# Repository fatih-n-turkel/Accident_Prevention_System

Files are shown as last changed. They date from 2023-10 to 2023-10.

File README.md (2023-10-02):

# Accident_Prevention_System
Accident Prevention System like TESLA cars. (PCB + Code Design)

(https://www.youtube.com/watch?v=p_svqTvp0FE) As shown in the video, TESLA vehicles prevent accidents by autonomously moving to the most suitable place when they suddenly encounter obstacles. This system has been simulated in this project. It can be used in hobby electronic devices. For example, if the vehicle is driving on a straight road and suddenly detects an obstacle from the left side, it will pass to the right (right corner) if the right side is available. If not, it will move to the most available place, otherwise it will stop.

In the hardware design, I got help from the open source designs of SparkFun.

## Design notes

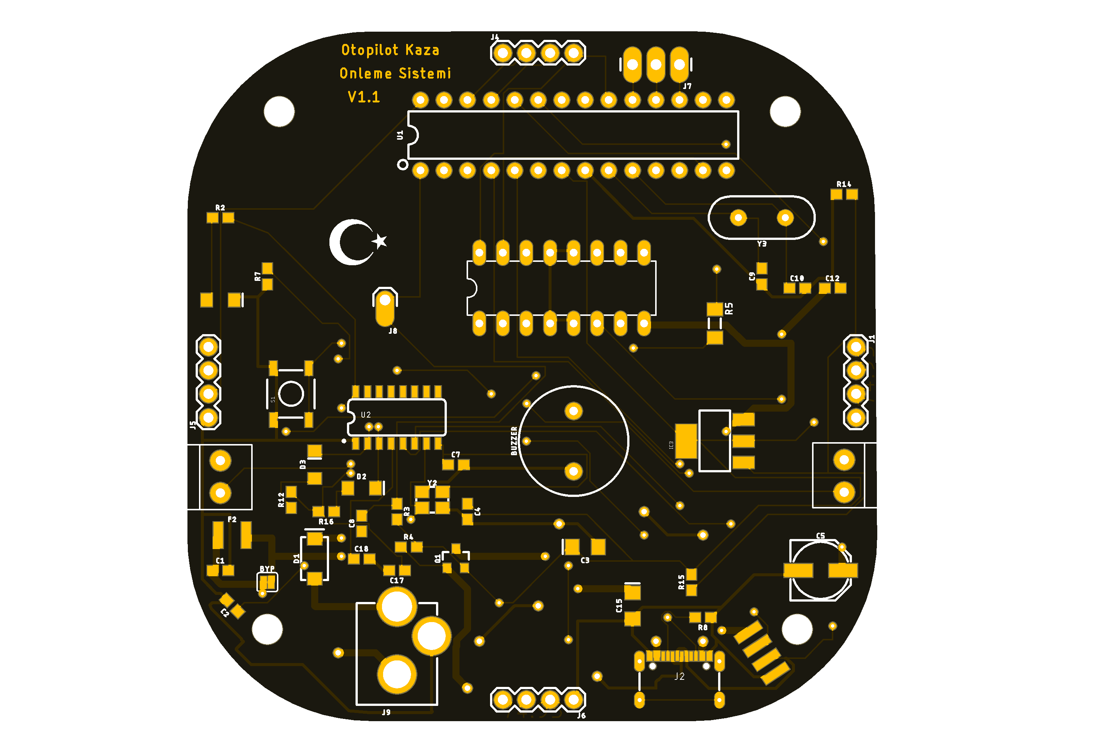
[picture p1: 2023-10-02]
KO_V31.png

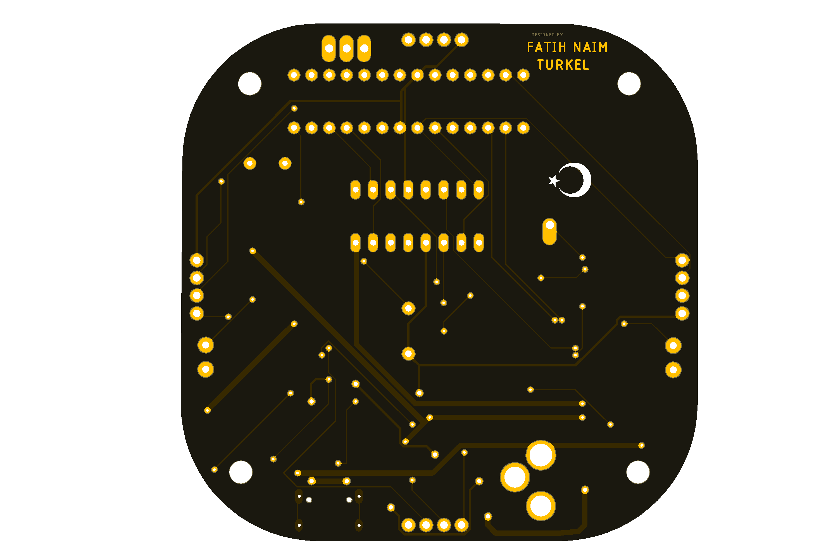
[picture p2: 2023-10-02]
KO_V32.png

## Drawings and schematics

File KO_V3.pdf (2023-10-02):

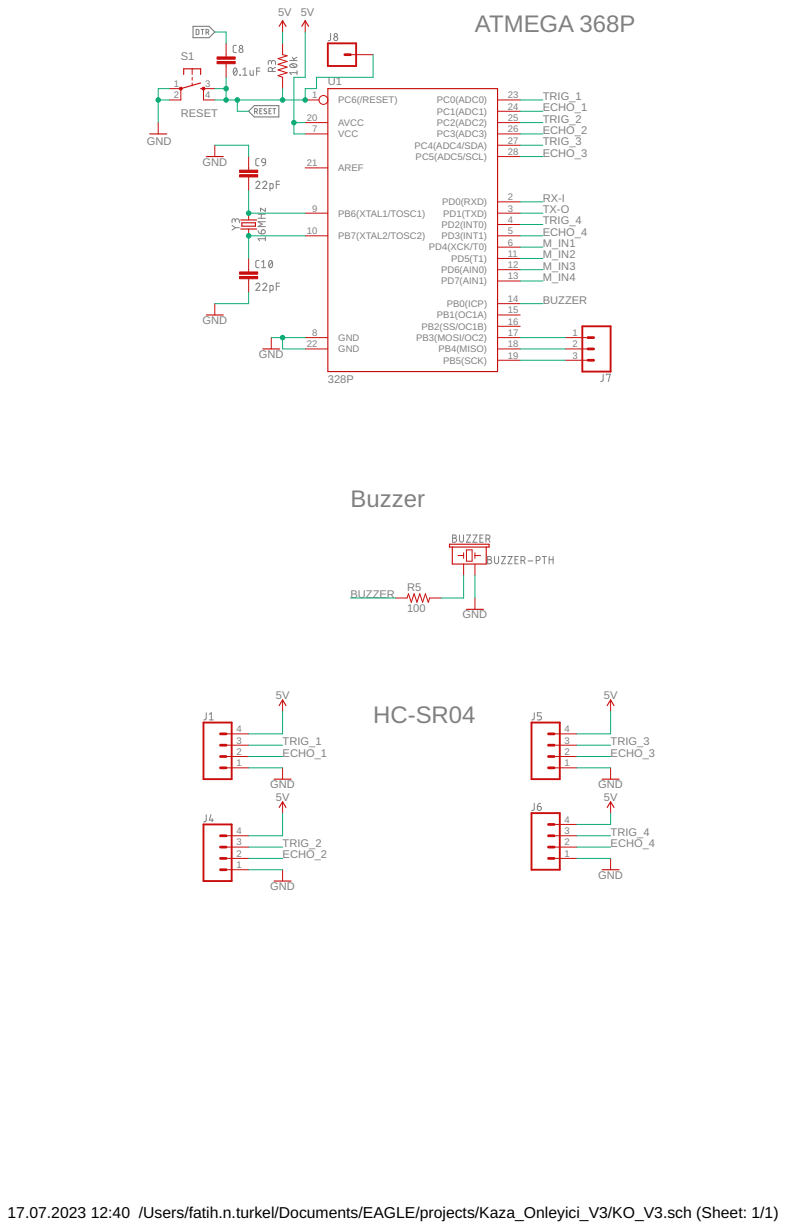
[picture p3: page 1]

17.07.2023 12:40 /Users/fatih.n.turkel/Documents/EAGLE/projects/Kaza_Onleyici_V3/KO_V3.sch (Sheet: 1/1)

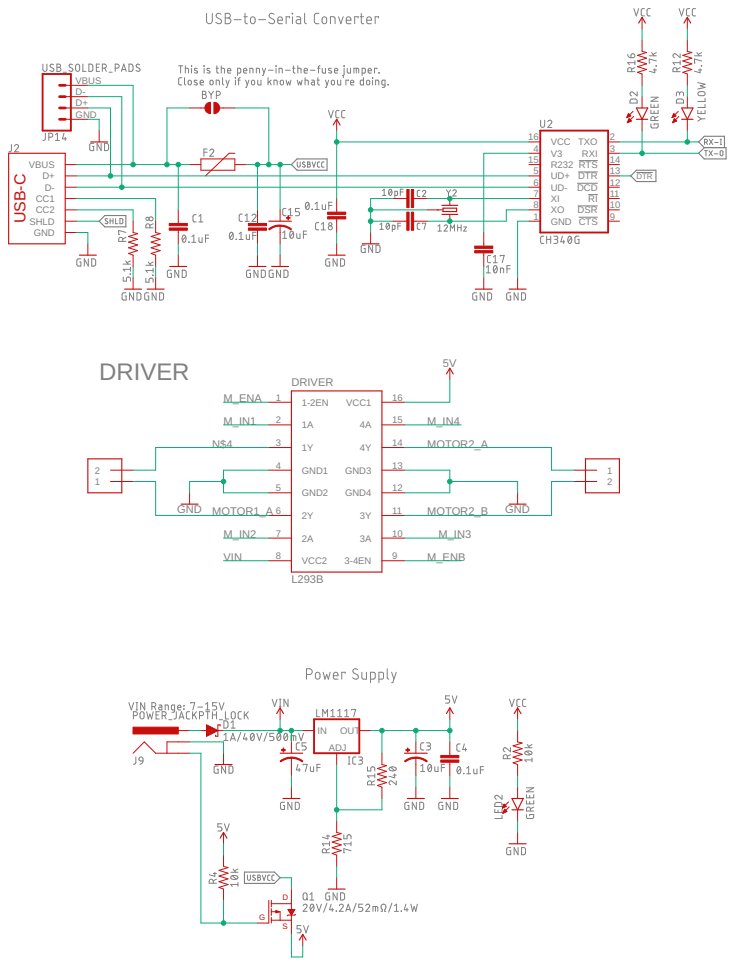
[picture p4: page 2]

DTR U

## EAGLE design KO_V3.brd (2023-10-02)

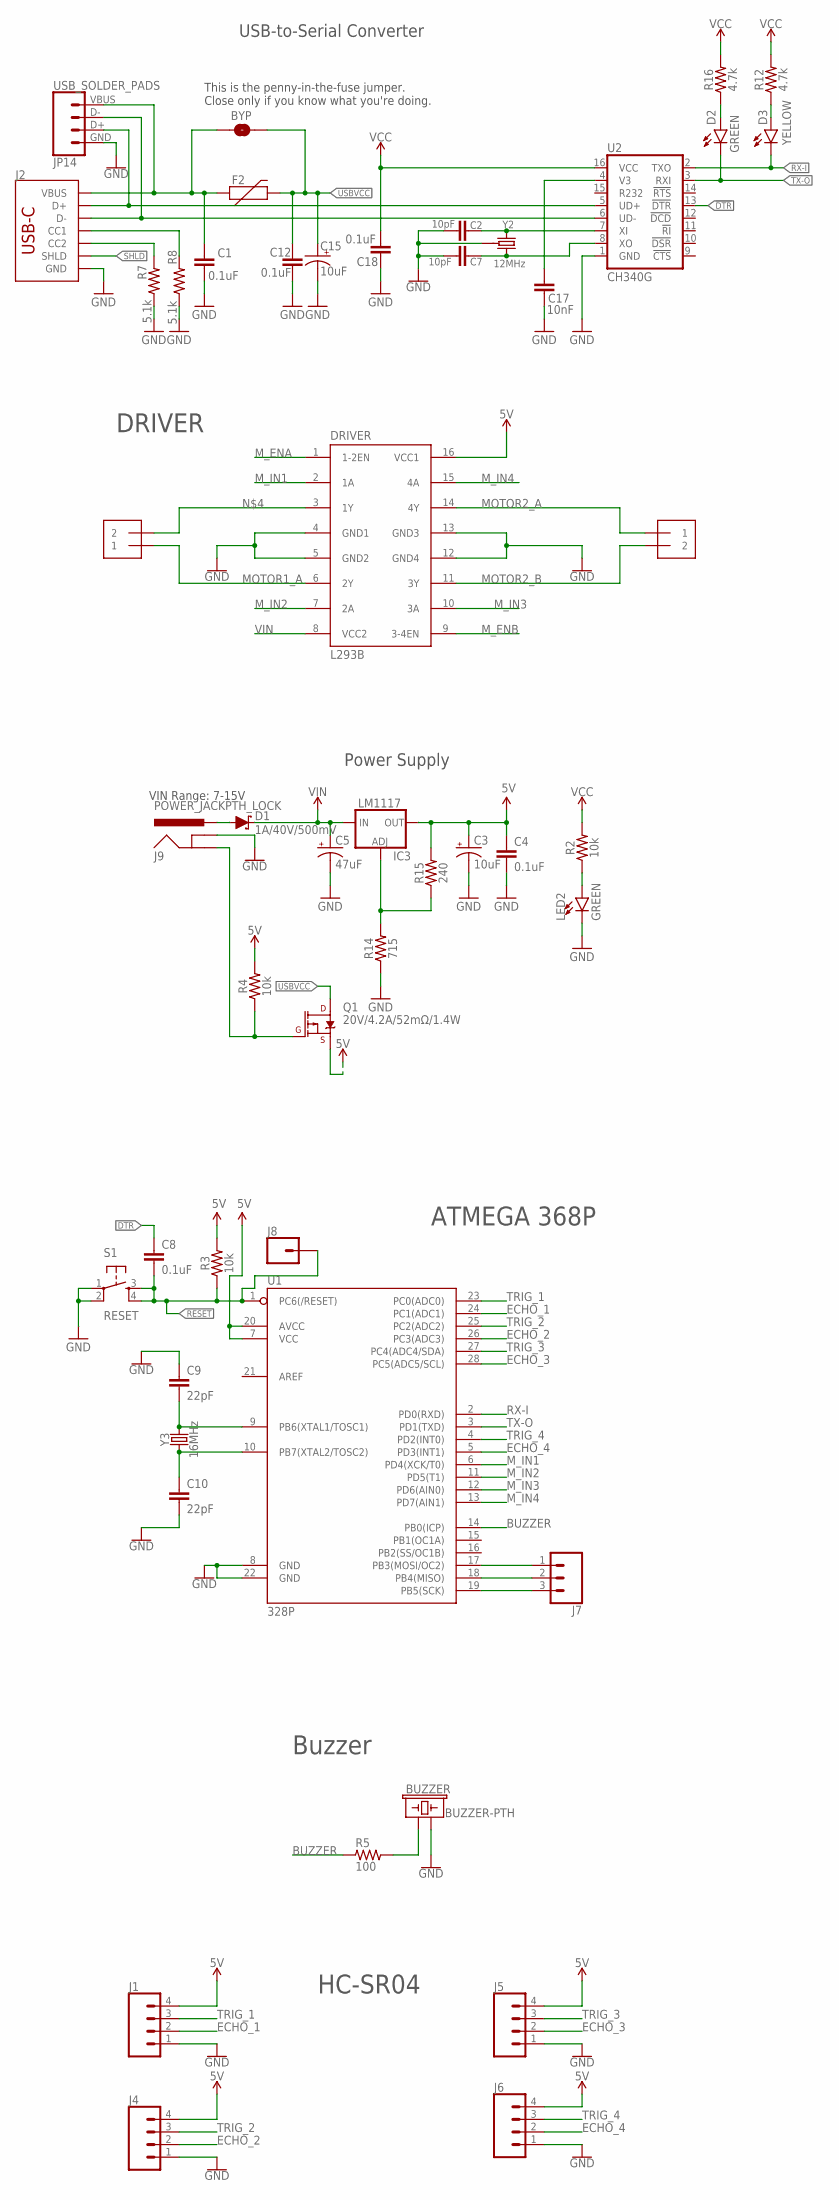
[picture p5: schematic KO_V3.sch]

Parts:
BUZZER: BUZZER-PTH; BUZZER-12MM
BYP: JUMPER-SMT_2_NO_SILK; SMT-JUMPER_2_NO_SILK
C1, C4, C8, C12, C18: 0.1uF; 0603
C2, C7: 10pF; 0603
C3, C15: 10uF; EIA3216
C5: 47uF; PANASONIC_D
C9, C10: 22pF; 0603
C17: 10nF; 0603
D1: 1A/40V/500mV; SMA-DIODE
D2: GREEN; LED-1206
D3: YELLOW; LED-1206-HIDDENSILK
DRIVER: L293B; DIL16
F2: 6V/2A; 1210
IC3: LM1117; SOT223
J1, J4, J5, J6: CONN_04; 1X04
J2: USB Female Type C Connector; USB-C-16P-2LAYER-PADS
J7: CONN_03LONGPADS; 1X03_LONGPADS
J8: CONN_01OFFSET; 1X01_OFFSET
J9: POWER_JACKPTH_LOCK; POWER_JACK_PTH_LOCK
JP14: USB_SOLDER_PADS; USB-SOLDER-PADS
LED2: GREEN; LED-1206
MOTOR_1, MOTOR_2: 1X2-3.5MM
Q1: 20V/4.2A/52mΩ/1.4W; SOT23-3
R2, R3, R4: 10k; 0603
R5: 100; RC-MASTER-SMD_R1206MP
R7, R8: 5.1k; 0603
R12, R16: 4.7k; 0603
R14: 715; 0603
R15: 240; 0603
S1: RESET; TACTILE-SWITCH-SMD
U1: 328P; DIP28
U2: CH340G; SO016
Y2: 12MHz; CRYSTAL-SMD-3.2X2.5MM
Y3: 16MHz; HC49US

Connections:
5V: C3.+, C4.1, DRIVER.16 (VCC1), IC3.2 (OUT), IC3.4 (OUT), J1.4, J4.4, J5.4, J6.4, Q1.2 (S), R3.2, R4.2, R15.2, U1.7 (VCC), U1.20 (AVCC)
!DTR!: U2.13 (!DTR)
BUZZER: R5.1, U1.14 (PB0(ICP))
CC1: J2.A5 (CC1), R8.2
CC2: J2.B5 (CC2), R7.2
D+: J2.A6 (D+), J2.B6 (D+), JP14.D+ (3), U2.5 (UD+)
D-: J2.A7 (D-), J2.B7 (D-), JP14.D- (2), U2.6 (UD-)
DTR: C8.1
ECHO_1: J1.2, U1.24 (PC1(ADC1))
ECHO_2: J4.2, U1.26 (PC3(ADC3))
ECHO_3: J5.2, U1.28 (PC5(ADC5/SCL))
ECHO_4: J6.2, U1.5 (PD3(INT1))
GND: BUZZER.- (2), C1.2, C2.2, C3.-, C4.2, C5.-, C7.2, C9.1, C10.2, C12.2, C15.-, C17.2, C18.2, DRIVER.4 (GND1), DRIVER.5 (GND2), DRIVER.12 (GND4), DRIVER.13 (GND3), J1.1, J2.GND, J2.GND2 (GND), J4.1, J5.1, J6.1, J9.GNDBREAK, JP14.GND (4), LED2.C, R7.1, R8.1, R14.1, S1.1, S1.2, U1.8 (GND), U1.22 (GND), U2.1 (GND), Y2.2 (GND), Y2.4 (GND)
INSERT: J9.GND, Q1.1 (G), R4.1
MOTOR1_A: DRIVER.6 (2Y), MOTOR_2.1
MOTOR2_A: DRIVER.14 (4Y), MOTOR_1.1
MOTOR2_B: DRIVER.11 (3Y), MOTOR_1.2
M_ENA: DRIVER.1 (1-2EN)
M_ENB: DRIVER.9 (3-4EN)
M_IN1: DRIVER.2 (1A), U1.6 (PD4(XCK/T0))
M_IN2: DRIVER.7 (2A), U1.11 (PD5(T1))
M_IN3: DRIVER.10 (3A), U1.12 (PD6(AIN0))
M_IN4: DRIVER.15 (4A), U1.13 (PD7(AIN1))
unnamed: C17.1, U2.4 (V3)
unnamed: C7.1, U2.8 (XO), Y2.3 (2)
unnamed: LED2.A, R2.1
unnamed: DRIVER.3 (1Y), MOTOR_2.2
unnamed: D2.A, R16.1
unnamed: BUZZER.+ (1), R5.2
unnamed: C2.1, U2.7 (XI), Y2.1
unnamed: D3.A, R12.1
unnamed: C9.2, U1.9 (PB6(XTAL1/TOSC1)), Y3.2
unnamed: C10.1, U1.10 (PB7(XTAL2/TOSC2)), Y3.1
unnamed: IC3.1 (ADJ), R14.2, R15.1
unnamed: J7.3, U1.19 (PB5(SCK))
unnamed: J7.2, U1.18 (PB4(MISO))
unnamed: J7.1, U1.17 (PB3(MOSI/OC2))
PWRIN: D1.A, J9.PWR
RESET: C8.2, J8.1, R3.1, S1.3, S1.4, U1.1 (PC6(/RESET))
RX-I: D3.C, U1.2 (PD0(RXD)), U2.2 (TXO)
SHLD: J2.SHLD1 (SHLD), J2.SHLD2 (SHLD), J2.SHLD3 (SHLD), J2.SHLD4 (SHLD)
TRIG_1: J1.3, U1.23 (PC0(ADC0))
TRIG_2: J4.3, U1.25 (PC2(ADC2))
TRIG_3: J5.3, U1.27 (PC4(ADC4/SDA))
TRIG_4: J6.3, U1.4 (PD2(INT0))
TX-O: D2.C, U1.3 (PD1(TXD)), U2.3 (RXI)
USBVCC: BYP.2, C12.1, C15.+, F2.2, Q1.3 (D)
VCC: C18.1, R2.2, R12.2, R16.2, U2.16 (VCC)
VIN: C5.+, D1.C, DRIVER.8 (VCC2), IC3.3 (IN)
VUSB: BYP.1, C1.1, F2.1, J2.VBUS1 (VBUS), J2.VBUS2 (VBUS), JP14.VBUS (1)

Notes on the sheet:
DRIVER
HC-SR04
Buzzer
ATMEGA 368P
USB-to-Serial Converter
This is the penny-in-the-fuse jumper. Close only if you know what you're doing.
Power Supply
VIN Range: 7-15V

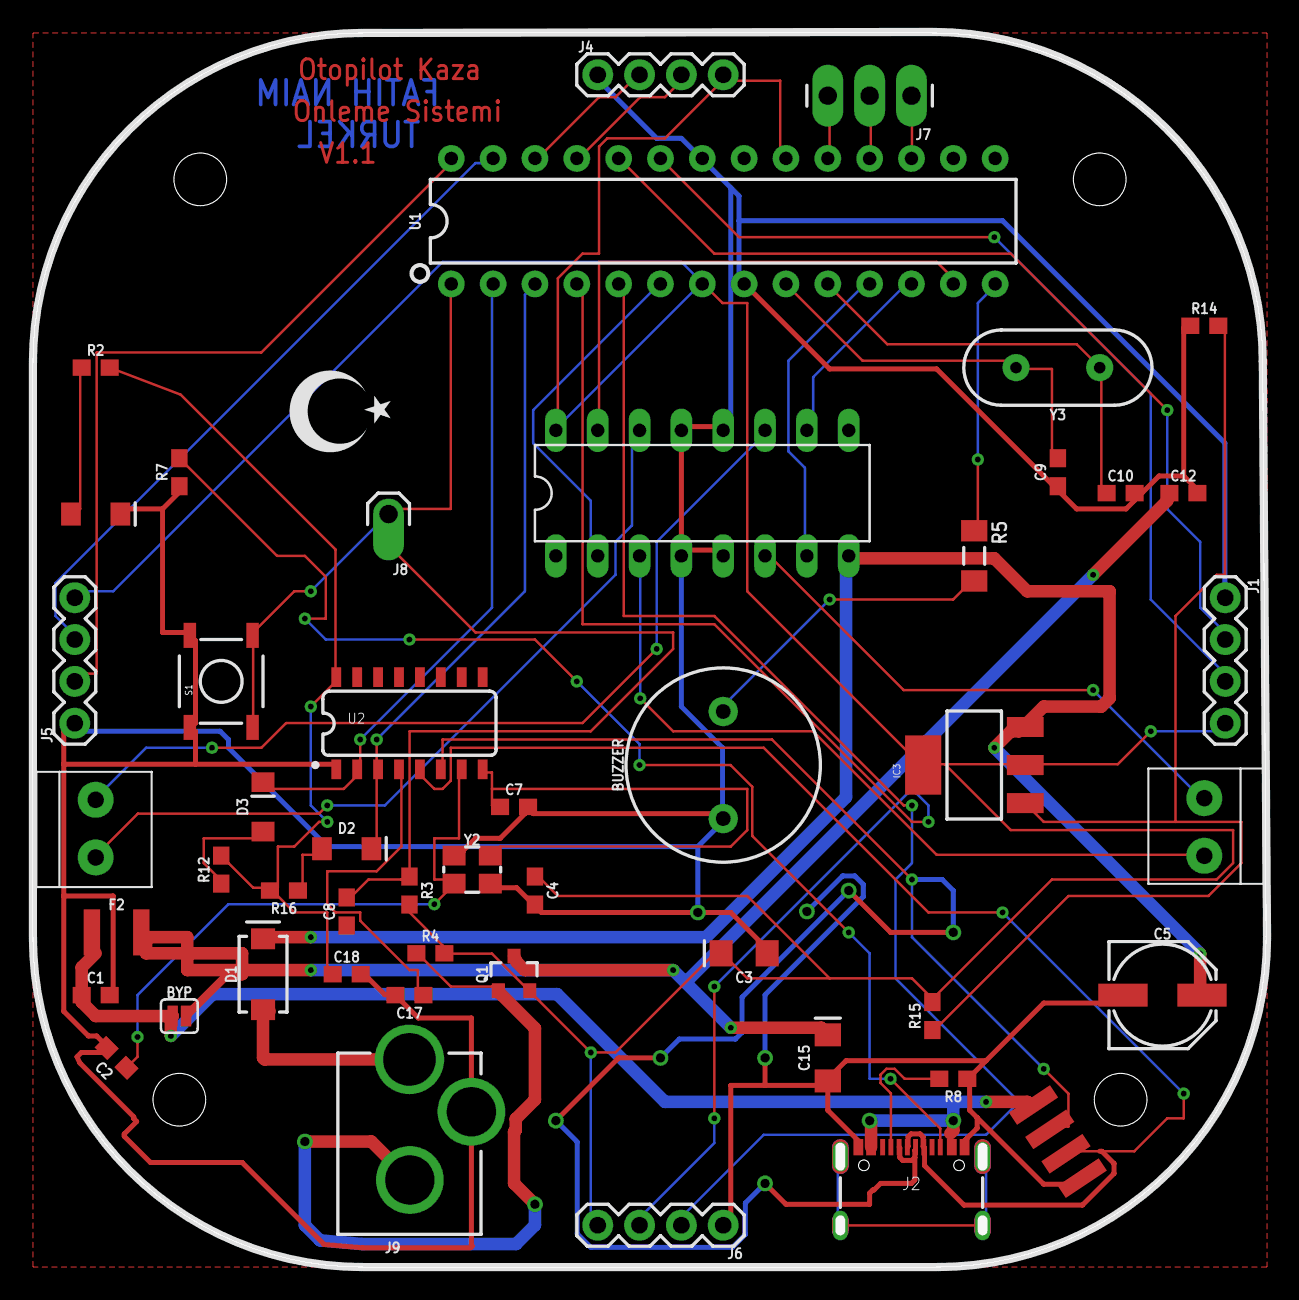
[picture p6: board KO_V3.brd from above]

Board: 2 copper layers, 74.9 x 74.9 mm, 51 parts (1 on the bottom side), 46 nets.

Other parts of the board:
U$2, U$4: TR_MINI

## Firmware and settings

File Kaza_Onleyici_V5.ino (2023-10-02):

const int trigPin1 = 2;   // HC-SR04 1. trig pini
const int echoPin1 = 3;   // HC-SR04 1. echo pini
const int trigPin2 = 4;   // HC-SR04 2. trig pini
const int echoPin2 = 5;   // HC-SR04 2. echo pini
const int trigPin3 = 6;   // HC-SR04 3. trig pini
const int echoPin3 = 7;   // HC-SR04 3. echo pini
const int trigPin4 = 8;   // HC-SR04 4. trig pini
const int echoPin4 = 9;   // HC-SR04 4. echo pini

const int motorPin1A = 10;  // Sol motor A pin
const int motorPin1B = 11;  // Sol motor B pin
const int motorPin2A = 12;  // Sağ motor A pin
const int motorPin2B = 13;  // Sağ motor B pin

const int buzzerPin = A0;  // Buzzer pin

int distanceThreshold = 5; // Yakın mesafe eşiği (5 cm olarak varsayıyoruz)

void setup() {
  pinMode(motorPin1A, OUTPUT);
  pinMode(motorPin1B, OUTPUT);
  pinMode(motorPin2A, OUTPUT);
  pinMode(motorPin2B, OUTPUT);

  pinMode(buzzerPin, OUTPUT);

  pinMode(trigPin1, OUTPUT);
  pinMode(echoPin1, INPUT);
  pinMode(trigPin2, OUTPUT);
  pinMode(echoPin2, INPUT);
  pinMode(trigPin3, OUTPUT);
  pinMode(echoPin3, INPUT);
  pinMode(trigPin4, OUTPUT);
  pinMode(echoPin4, INPUT);

  Serial.begin(9600);
}

void loop() {
  int distance1 = getDistance(trigPin1, echoPin1);
  int distance2 = getDistance(trigPin2, echoPin2);
  int distance3 = getDistance(trigPin3, echoPin3);
  int distance4 = getDistance(trigPin4, echoPin4);

  Serial.print("Distance 1: ");
  Serial.println(distance1);
  Serial.print("Distance 2: ");
  Serial.println(distance2);
  Serial.print("Distance 3: ");
  Serial.println(distance3);
  Serial.print("Distance 4: ");
  Serial.println(distance4);
  Serial.println("-----------------");

  // Sol taraftan engel yaklaşırsa
  if (distance1 < distanceThreshold) {
    Serial.print("SOLDA ENGEL TESPIT EDILDI..");
    buzzerAlert();
      turnRight();
    Serial.print("saga donuluyor..");
      delay(1000);
      forward();
    Serial.print("Duz gidiliyor..");
      delay(1000);
      turnLeft();
    Serial.print("sola donuluyor..");
      delay(1000);
      forward();
    Serial.print("Duz gidiliyor..");
      delay(1000);
      turnLeft();
    Serial.print("sola donuluyor..");
      delay(1000);
      forward();
    Serial.print("Duz gidiliyor..");
      delay(1000);
      turnRight();
    Serial.print("saga donuluyor..");
      delay(1000);
    
  }
  // Sağ taraftan engel yaklaşırsa
  else if (distance2 < distanceThreshold) {
    Serial.print("SAGDA ENGEL TTESPIT EDILDI..");
    buzzerAlert();
      turnLeft();
    Serial.print("sola donuluyor..");
      delay(1000);
      forward();
    Serial.print("Duz gidiliyor..");
      delay(1000);
      turnRight();
    Serial.print("saga donuluyor..");
      delay(1000);
      forward();
    Serial.print("Duz gidiliyor..");
      delay(1000);
      turnRight();
    Serial.print("saga donuluyor..");
      delay(1000);
      forward();
    Serial.print("Duz gidiliyor..");
      delay(1000);
      turnLeft();
    Serial.print("sola donuluyor..");
      delay(1000);
    
  }
  // Ön taraftan engel yaklaşırsa
  else if (distance3 < distanceThreshold) {
    Serial.print("ONDE ENGEL TESPIT EDILDI..");
    buzzerAlert();
    if (distance4 > distanceThreshold) {
      reverse();
    } else {
      stopMotors();
    }
    
  }
  // Arka taraftan engel yaklaşırsa
  else if (distance4 < distanceThreshold) {
    Serial.print("ARKADA ENGEL TESPIT EDILDI..");
    buzzerAlert();
    if (distance1 > distanceThreshold) {
      forward();
    } else {
      stopMotors();
    }
    
  }
  // Tüm yönlere engel yaklaşırsa
  else if (distance1 < distanceThreshold && distance2 < distanceThreshold && distance3 < distanceThreshold && distance4 < distanceThreshold) {
    Serial.print("HER YONDE ENGEL TESPIT EDILDI..");
    buzzerAlert();
    stopMotors();
    
  }
  // Engel yoksa ileri git
  else {
    Serial.print("ENGEL YOK..");
    forward();
  }

  delay(100);
}

int getDistance(int trigPin, int echoPin) {
  digitalWrite(trigPin, LOW);
  delayMicroseconds(2);
  digitalWrite(trigPin, HIGH);
  delayMicroseconds(10);
  digitalWrite(trigPin, LOW);
  long duration = pulseIn(echoPin, HIGH);
  int distance = duration * 0.034 / 2;
  return distance;
}

void forward() {
  digitalWrite(motorPin1A, HIGH);
  digitalWrite(motorPin1B, LOW);
  digitalWrite(motorPin2A, HIGH);
  digitalWrite(motorPin2B, LOW);
}

void reverse() {
  digitalWrite(motorPin1A, LOW);
  digitalWrite(motorPin1B, HIGH);
  digitalWrite(motorPin2A, LOW);
  digitalWrite(motorPin2B, HIGH);
}

void turnLeft() {
  digitalWrite(motorPin1A, LOW);
  digitalWrite(motorPin1B, HIGH);
  digitalWrite(motorPin2A, HIGH);
  digitalWrite(motorPin2B, LOW);
}

void turnRight() {
  digitalWrite(motorPin1A, HIGH);
  digitalWrite(motorPin1B, LOW);
  digitalWrite(motorPin2A, LOW);
  digitalWrite(motorPin2B, HIGH);
}

void stopMotors() {
  digitalWrite(motorPin1A, LOW);
  digitalWrite(motorPin1B, LOW);
  digitalWrite(motorPin2A, LOW);
  digitalWrite(motorPin2B, LOW);
}

void buzzerAlert() {
  for (int i = 0; i < 2; i++) {
    digitalWrite(buzzerPin, HIGH);
    delay(500);
    digitalWrite(buzzerPin, LOW);
    delay(500);
  }
  }

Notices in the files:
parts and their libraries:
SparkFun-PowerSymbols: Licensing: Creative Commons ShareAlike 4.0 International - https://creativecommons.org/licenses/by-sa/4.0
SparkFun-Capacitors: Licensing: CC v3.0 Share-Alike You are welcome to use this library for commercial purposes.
